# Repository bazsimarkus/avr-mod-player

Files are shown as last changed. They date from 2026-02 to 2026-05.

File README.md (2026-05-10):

# avr-mod-player

An ATmega32-based ProTracker MOD music player with AM29F040B parallel flash memory and stereo PWM audio output. Program a MOD file onto the flash chip, plug it in, and music starts playing.

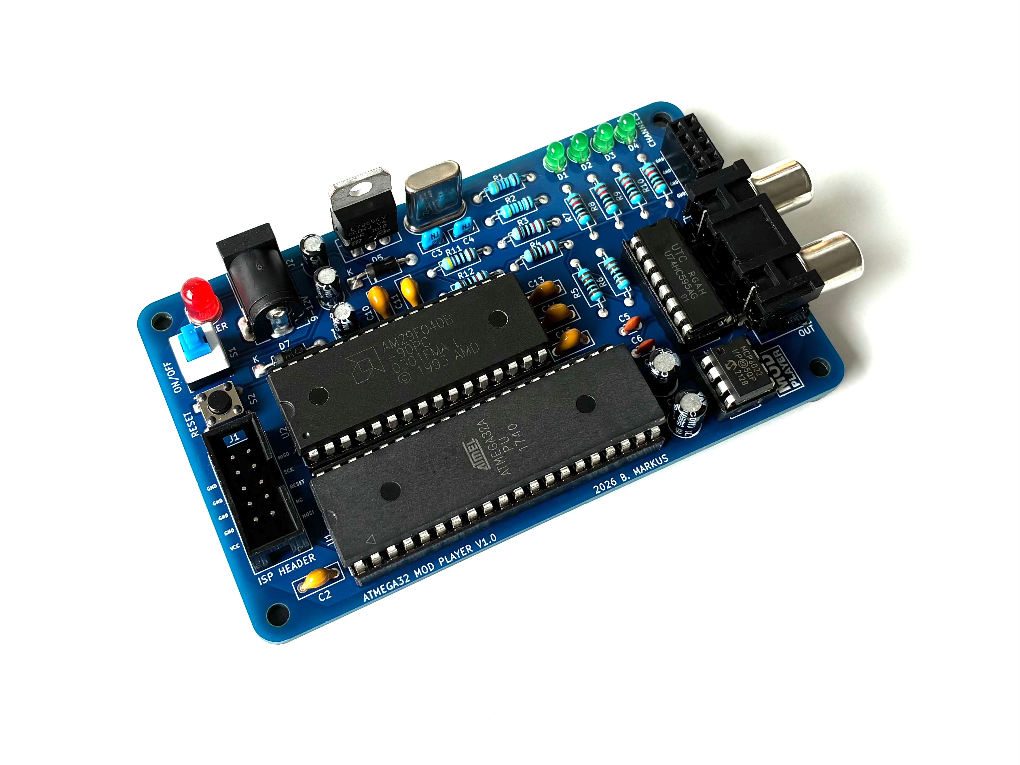
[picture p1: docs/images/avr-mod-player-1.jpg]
AVR MOD Player


---

## Table of Contents

- [Overview](#overview)
- [Features](#features)
- [Getting Started](#getting-started)
  - [What You Need](#what-you-need)
  - [Programming the Flash Chip](#programming-the-flash-chip)
  - [Building and Flashing the Firmware](#building-and-flashing-the-firmware)
- [Schematic](#schematic)
  - [Bill of Materials for the Main Board](#bill-of-materials-for-the-main-board)
- [How It Works](#how-it-works)
  - [Flash Memory Interface](#flash-memory-interface)
  - [Audio Output](#audio-output)
  - [MOD Playback Engine](#mod-playback-engine)
  - [Channel Activity LEDs](#channel-activity-leds)
  - [Power Supply and Protection](#power-supply-and-protection)
- [Speaker Extension Board](#speaker-extension-board)
  - [Bill of Materials for the Speaker Extension Board](#bill-of-materials-for-the-speaker-extension-board)
- [Documentation](#documentation)
- [Acknowledgments](#acknowledgments)

---

## Overview

This is a standalone hardware MOD file player built around the ATmega32A microcontroller. It reads ProTracker .MOD files directly from an AM29F040B parallel NOR flash chip and outputs stereo audio through RCA connectors using PWM and analog filtering. Four green LEDs flash in time with the music, one per channel, showing which voices are active.

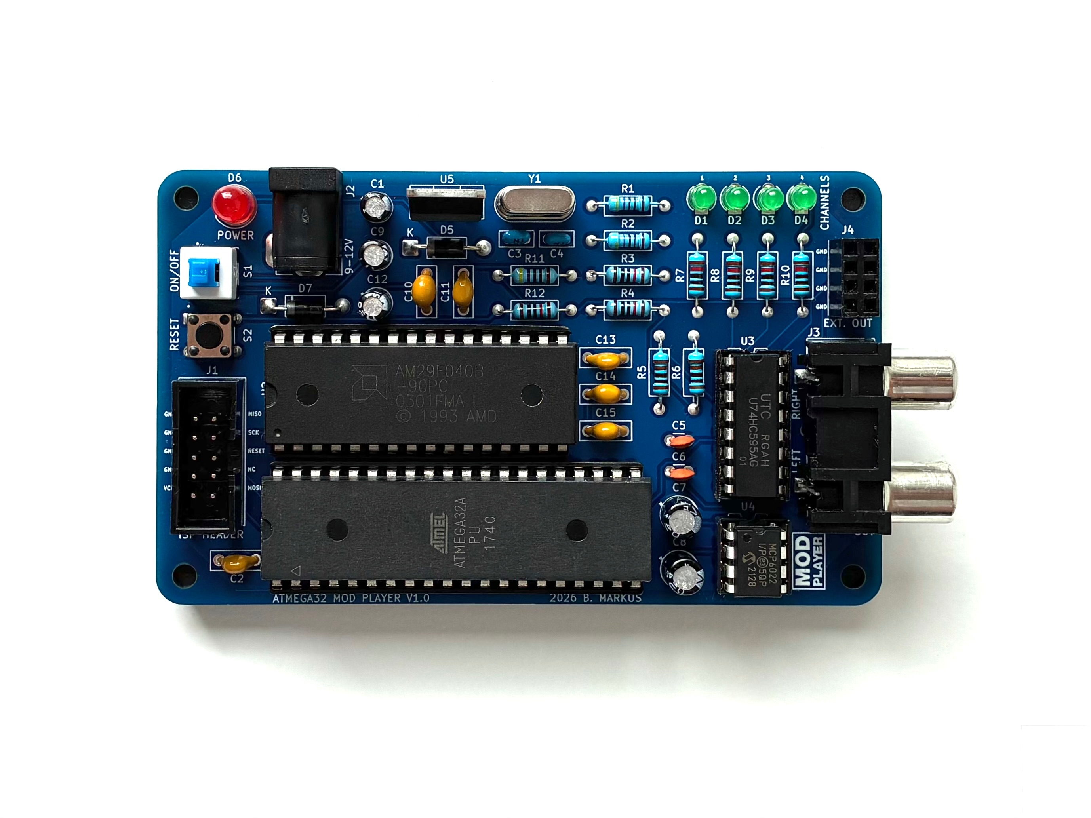
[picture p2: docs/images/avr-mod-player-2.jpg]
AVR MOD Player Top View


The concept is simple: program a MOD file onto the flash chip, plug it into the socket, flip the power switch, and music starts playing immediately. No SD cards, no file systems, no menus. Just a chip full of music and a microcontroller that knows how to play it. If you want to listen to a different track, pull the flash chip out of its socket, erase it, program a new file, and put it back.

My main inspiration was [MadWizard's AVR MOD player](https://www.madwizard.org/electronics/projects/modplayer). That project also used the AM29F040 flash chip, which led me down this path. Since I had no way to program these chips, I ended up designing my own flash programmer, available as a separate project: [amd-flash-programmer](https://github.com/bazsimarkus/amd-flash-programmer).

---

## Features

- ATmega32A microcontroller running at 16 MHz external crystal
- AM29F040B 512KB parallel NOR flash for MOD file storage (socketed for easy swapping)
- Stereo audio output through dual RCA connectors
- MCP6022 dual rail-to-rail op-amp based analog output filtering
- 74HC595 shift register driving four green 3mm channel activity LEDs
- 4-channel ProTracker MOD format playback with effects (arpeggio, portamento, vibrato, volume slide, and more)
- 16 kHz PWM sample rate via Timer1, stereo hard-panned per ProTracker convention (channels 1 and 4 left, channels 2 and 3 right)
- 10-pin ISP header for in-circuit programming via USBasp
- 9-12V DC barrel jack power input with L7805 5V regulator
- 1N5819 Schottky diode protection preventing backfeed between DC jack and ISP programmer power
- ON/OFF toggle switch and reset button
- Pin header for the optional LM386 speaker extension board
- Designed in KiCad, full schematic and PCB files included

---

## Getting Started

### What You Need

- The assembled AVR MOD Player board
- A USBasp programmer (or any AVR ISP programmer)
- A way to program the AM29F040B flash chip (e.g. [amd-flash-programmer](https://github.com/bazsimarkus/amd-flash-programmer))
- A ProTracker .MOD file (max 512KB to fit on the flash chip)
- avr-gcc and avrdude installed on your system
- An RCA audio cable or the speaker extension board for output

### Programming the Flash Chip

1. Find a MOD file you want to play. [The Mod Archive](https://modarchive.org/) has a large collection of free tracks. Some personal favorites: Maktone - Vanishing Colors, LHS - It's a Good Day, Random Voice - Monday.

2. Remove the AM29F040B from its socket on the player board.

3. Program the raw .MOD file onto the flash chip starting at address 0x00000 using the [amd-flash-programmer](https://github.com/bazsimarkus/amd-flash-programmer) or any compatible flash programmer.

4. Place the programmed flash chip back into the socket on the player board.

5. Flip the power switch. The music starts playing immediately.

### Building and Flashing the Firmware

The firmware is a single C source file (`avr-mod-player/main.c`) targeting the ATmega32A at 16 MHz. It has no external dependencies beyond standard avr-libc. It links against libm for the math routines.

#### Method 1: Command line with avr-gcc and avrdude

Install avr-gcc and avrdude for your platform (on Debian/Ubuntu: `sudo apt install gcc-avr avr-libc avrdude`; on Windows, install WinAVR or the Microchip AVR toolchain).

Navigate to the `avr-mod-player` directory and run:

```sh
avr-gcc -mmcu=atmega32 -DF_CPU=16000000UL -O1 \
    -funsigned-char -funsigned-bitfields \
    -ffunction-sections -fdata-sections \
    -fpack-struct -fshort-enums \
    -Wall -o main.elf main.c -lm

avr-objcopy -O ihex main.elf main.hex
```

Then flash with your USBasp programmer:

```sh
avrdude -c usbasp -p m32 -U flash:w:main.hex
```

#### Method 2: MPLAB X IDE

The repository includes an MPLAB X IDE project in the `avr-mod-player/nbproject` directory. The project has two build configurations:

- **default**: Compiles only, produces the hex file.
- **flash**: Identical to default, but runs avrdude automatically after a successful build to flash the connected board via USBasp. The post-build step is:

```
avrdude -c usbasp -p m32 -U flash:w:${ImagePath}
```

With the flash configuration selected, clicking Build Main Project compiles the firmware and programs the board in a single step.

The project was developed with MPLAB X IDE v6.25 and the Microchip ATmega_DFP 3.3.279 device pack. The compiler is avr-gcc 5.4.0.

---

## Schematic

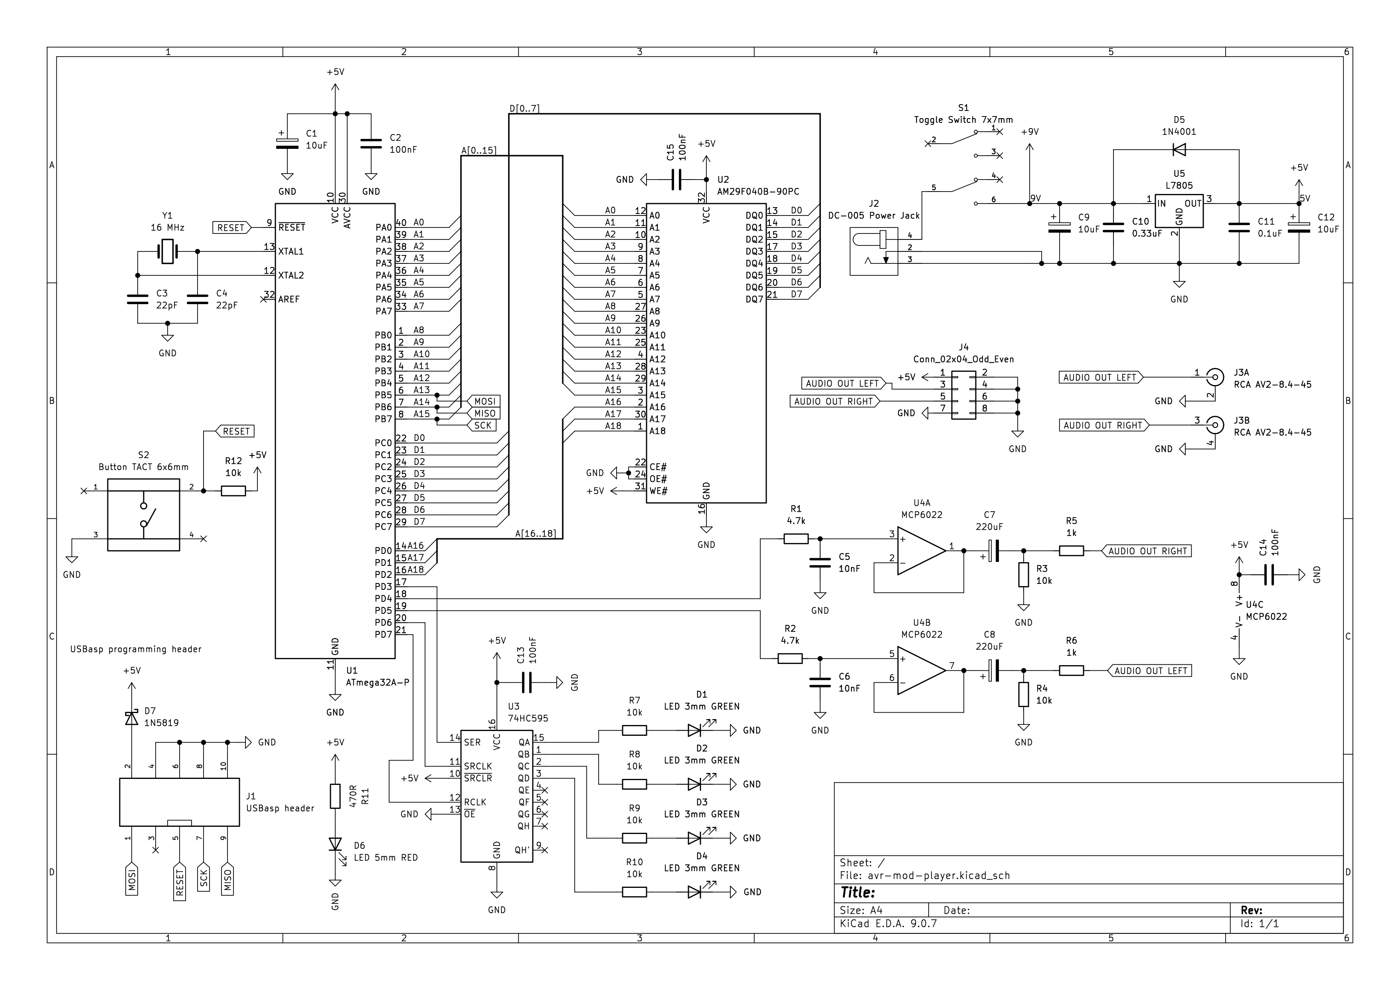
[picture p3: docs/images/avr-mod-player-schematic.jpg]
AVR MOD Player Schematic


The full KiCad project files (schematic, PCB layout, and project file) are in the `schematic/` directory.

### Bill of Materials for the Main Board

| Ref | Value | Description | Qty |
|-----|---|---|-----|
| **ICs** ||||
| U1 | ATmega32A-P | 16 MHz, 32 KB Flash, 2 KB SRAM, DIP-40 | 1 |
| U2 | AM29F040B-90PC | 4 Mbit NOR flash (512K×8), 90 ns, DIP-32 | 1 |
| U3 | 74HC595 | 8-bit shift register, 3-state outputs, DIP-16 | 1 |
| U4 | MCP6022 | Dual rail-to-rail op-amp, DIP-8 | 1 |
| U5 | L7805 | 5 V 1.5 A linear voltage regulator, TO-220 | 1 |
| **Crystal** ||||
| Y1 | 16 MHz | HC49-U vertical | 1 |
| **Capacitors (polarized)** ||||
| C1 | 10 µF | Electrolytic, radial, D4.0 mm P2.00 mm | 1 |
| C7 | 220 µF | Electrolytic, radial, D5.0 mm P2.00 mm | 1 |
| C8 | 220 µF | Electrolytic, radial, D5.0 mm P2.00 mm | 1 |
| C9 | 10 µF | Electrolytic, radial, D4.0 mm P2.00 mm | 1 |
| C12 | 10 µF | Electrolytic, radial, D4.0 mm P2.00 mm | 1 |
| **Capacitors (unpolarized)** ||||
| C2 | 100 nF | Film/MLCC, P5.00 mm | 1 |
| C3 | 22 pF | Ceramic, P2.50 mm | 1 |
| C4 | 22 pF | Ceramic, P2.50 mm | 1 |
| C5 | 10 nF | Ceramic disc, P2.50 mm | 1 |
| C6 | 10 nF | Ceramic disc, P2.50 mm | 1 |
| C10 | 0.33 µF | Film, P5.00 mm | 1 |
| C11 | 0.1 µF | Film, P5.00 mm | 1 |
| C13 | 100 nF | Film/MLCC, P5.00 mm | 1 |
| C14 | 100 nF | Film/MLCC, P5.00 mm | 1 |
| C15 | 100 nF | Film/MLCC, P5.00 mm | 1 |
| **Resistors (all 1/4 W axial)** ||||
| R1, R2 | 4.7 kΩ | PWM filter pull-up | 2 |
| R3, R4, R7, R8, R9, R10, R12 | 10 kΩ | Pull-ups / biasing / LED current limit | 7 |
| R5, R6 | 1 kΩ | Audio output series | 2 |
| R11 | 470 Ω | Power LED current limiter | 1 |
| **Diodes** ||||
| D1, D2, D3, D4 | LED 3 mm green | Channel activity indicators | 4 |
| D5 | 1N4001 | 50 V 1 A rectifier, DO-41 | 1 |
| D6 | LED 5 mm red | Power indicator | 1 |
| D7 | 1N5819 | 40 V 1 A Schottky, DO-41 (reverse polarity protection) | 1 |
| **Switches** ||||
| S1 | Toggle 7×7 mm DPDT | Power on/off (E-Switch TL2230OAF140) | 1 |
| S2 | Tact 6×6 mm | Reset (CUI TS02-66-100-BK-260-LCR-D) | 1 |
| **Connectors** ||||
| J1 | 2×5 shrouded box header | USBasp ISP header (Würth 61201021621) | 1 |
| J2 | DC-005 barrel jack | 2.1 mm center-positive | 1 |
| J3 | Dual RCA (AV2-8.4-45) | Stereo audio output | 1 |
| J4 | 2×4 pin socket | Speaker board expansion, 2.54 mm | 1 |
| **Recommended sockets** ||||
| - | 40-pin DIP socket | For U1 (ATmega32A) | 1 |
| - | 32-pin DIP socket | For U2 (AM29F040B) | 1 |
| - | 16-pin DIP socket | For U3 (74HC595) | 1 |
| - | 8-pin DIP socket | For U4 (MCP6022) | 1 |

---

## How It Works

### Flash Memory Interface

The AM29F040B is a 512KB parallel NOR flash chip in a 32-pin DIP package. The ATmega32A addresses it using nearly all of its available I/O pins:

- PORTA (PA0-PA7): Address lines A0-A7
- PORTB (PB0-PB7): Address lines A8-A15
- PORTD (PD0-PD2): Address lines A16-A18
- PORTC (PC0-PC7): Data bus DQ0-DQ7 (configured as input)

This gives 19 address lines, enough for the full 512KB address space. The chip enable (CE#) and output enable (OE#) pins are active (directly connected to ground), meaning the flash is always outputting data on the bus. The write enable (WE#) pin is pulled high permanently with a resistor, since the player board never writes to the flash. This simplified design was necessary because the ATmega32A does not have enough free pins to control WE# dynamically.

Reading a byte from flash is a single function call: set PORTA, PORTB, and the lower bits of PORTD to the desired address, wait two CPU cycles for the flash access time, then read PINC. At 16 MHz, this gives about 187 ns of access time, well within the 90 ns rating of the AM29F040B-90PC.

### Audio Output

Stereo audio is generated using Timer1 in 8-bit fast PWM mode. The two PWM outputs (OC1A on PD5 for left, OC1B on PD4 for right) run at a carrier frequency of 62.5 kHz (16 MHz / 256), which is well above the audible range.

The raw PWM signals pass through a low-pass filter built around the MCP6022 dual rail-to-rail op-amp. Each channel has its own filter section: a 10nF capacitor and a 4.7k resistor form the RC low-pass, and the op-amp buffers and drives the output through a 220uF coupling capacitor to the RCA connector. The coupling capacitor removes the DC offset so only the audio AC signal reaches the amplifier or speakers.

### MOD Playback Engine

The firmware implements a ProTracker-compatible 4-channel MOD player. Timer0 fires an interrupt at exactly 16,000 Hz, which pulls samples from a ring buffer and writes them to the PWM registers. The main loop continuously fills that buffer by mixing the four channels.

The MOD file format stores music as a sequence of patterns. Each pattern has 64 rows, and each row has four cells (one per channel). Each cell can trigger a sample at a given pitch, change the volume, or apply an effect. At startup, the firmware parses the MOD header from flash to locate the sample data and pattern data, then begins sequencing through the song.

The engine supports the following ProTracker effects:

- 0xy: Arpeggio
- 1xx: Portamento up
- 2xx: Portamento down
- 3xx: Tone portamento
- 4xy: Vibrato
- 9xx: Sample offset
- Axy: Volume slide
- Bxx: Pattern jump
- Cxx: Set volume
- Dxx: Pattern break
- Fxx: Set speed/tempo
- E1y/E2y: Fine portamento
- E9y: Retrigger note
- EAy/EBy: Fine volume slide
- ECy: Note cut

Pitch is calculated using 16.16 fixed-point arithmetic. The playback step for each channel is derived from the Amiga PAL clock constant (3,546,895 Hz) divided by the channel's current period value, scaled to the 16 kHz output rate. This gives sample-accurate pitch reproduction matching the original Amiga hardware.

The MOD file format specification used to build this player is included in the repository at `docs/mod-spec.txt` (sourced from [eblong.com/zarf/blorb/mod-spec.txt](https://www.eblong.com/zarf/blorb/mod-spec.txt)).

### Channel Activity LEDs

Four green 3mm LEDs (D1-D4) are driven by a 74HC595 shift register connected to three pins on PORTD. Each time a note triggers on a channel, the corresponding LED lights up for approximately 60 milliseconds (3 sequencer ticks). This creates a short flash locked to the beat, giving a visual indication of which channels are active. The LEDs are updated once per sequencer tick in the main audio loop.

### Power Supply and Protection

The board is powered from a 9-12V DC barrel jack. An L7805 voltage regulator provides the 5V rail for all digital and analog circuitry. A 1N4001 rectifier diode on the DC input provides reverse polarity protection.

A 1N5819 Schottky diode sits between the ISP header's VCC pin and the board's 5V rail. When the board is powered from the DC jack, the Schottky diode prevents the regulated 5V from backfeeding into the programmer. When the board is powered from the programmer (for firmware development without the DC supply connected), the Schottky diode conducts and powers the board from the programmer's VCC. This protects both the L7805 regulator and the programmer from conflicting voltage sources.

---

## Speaker Extension Board

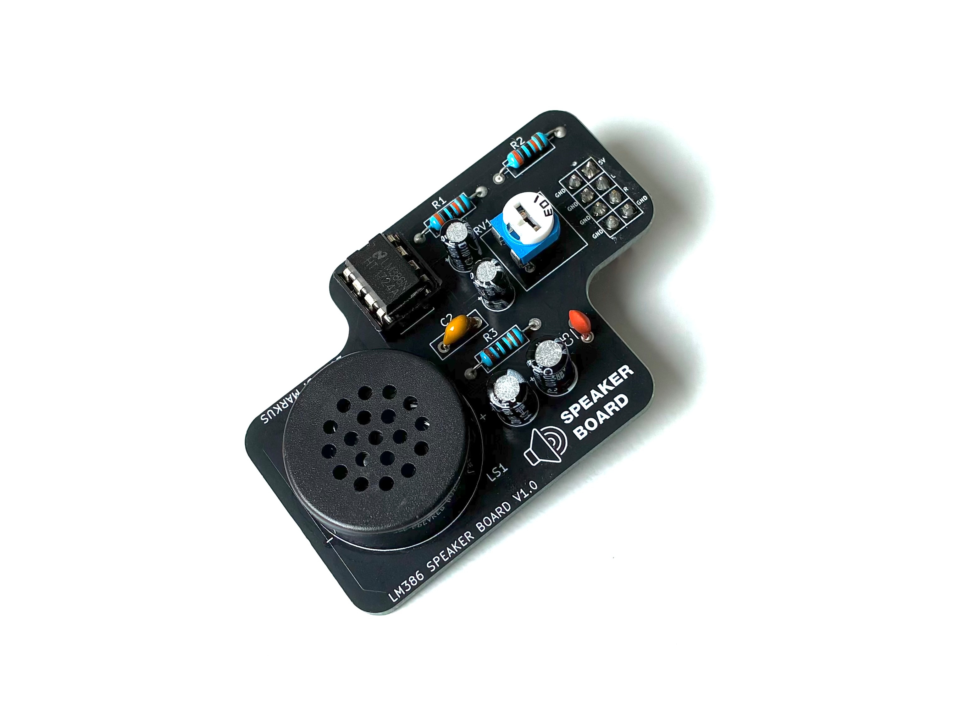
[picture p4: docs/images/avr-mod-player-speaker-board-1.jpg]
Speaker Extension Board


An optional LM386 speaker extension board can be connected to the 2x4 pin header (J4) on the main board. It mixes the left and right channels through two 300k resistors into a volume trimmer, feeds the signal through an LM386 audio power amplifier, and drives a small 23mm 8-ohm speaker. The board connects directly to the pin header and receives both audio signals and power from the main board.

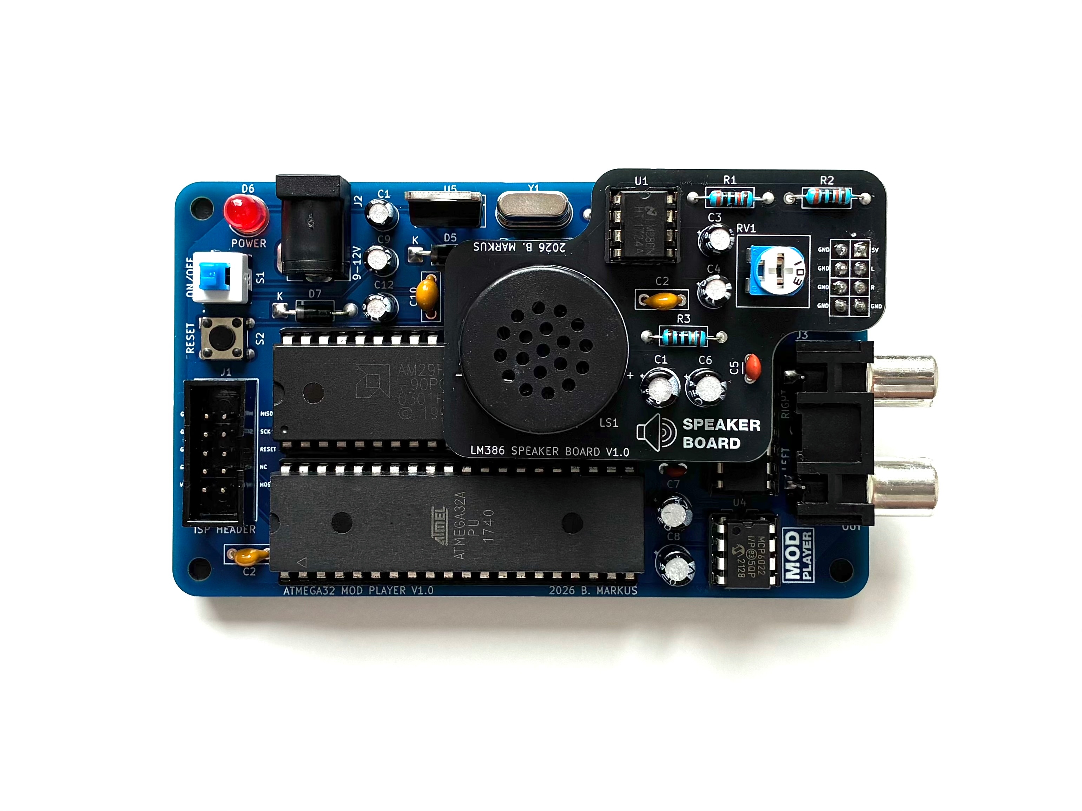
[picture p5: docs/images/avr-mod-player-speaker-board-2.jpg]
Speaker Extension Board connected to the main board


The KiCad project files for the speaker board are in `extension-boards/speaker-board/`.

### Bill of Materials for the Speaker Extension Board

| Ref | Value | Description | Qty |
|-----|---|---|-----|
| **ICs** ||||
| U1 | LM386 | Low-voltage audio power amplifier, DIP-8 | 1 |
| **Capacitors (polarized)** ||||
| C1 | 100 µF | Electrolytic, radial, D5.0 mm P2.00 mm | 1 |
| C3 | 1 µF | Electrolytic, radial, D4.0 mm P2.00 mm | 1 |
| C4 | 10 µF | Electrolytic, radial, D4.0 mm P2.00 mm (bypass) | 1 |
| C6 | 220 µF | Electrolytic, radial, D5.0 mm P2.00 mm (output coupling) | 1 |
| **Capacitors (unpolarized)** ||||
| C2 | 0.1 µF | Film, P5.00 mm (decoupling) | 1 |
| C5 | 47 nF | Ceramic disc, P2.50 mm (Zobel network) | 1 |
| **Resistors (all 1/4 W axial)** ||||
| R1, R2 | 300 kΩ | Input mixing (L + R → mono) | 2 |
| R3 | 10 Ω | Zobel network series | 1 |
| **Potentiometer** ||||
| RV1 | Trimpot 3362-P | Volume adjustment | 1 |
| **Speaker** ||||
| LS1 | CVS-2308 | 23 mm, 0.1 W, 8 Ω (CUI Devices) | 1 |
| **Connectors** ||||
| J1 | 2×4 pin header | Mates with main board J4, 2.54 mm vertical | 1 |
| **Recommended sockets** ||||
| - | 8-pin DIP socket | For U1 (LM386) | 1 |

---

## Documentation

The `docs/` directory contains:

- `mod-spec.txt`: The ProTracker MOD file format specification used as reference for the playback engine (from [eblong.com](https://www.eblong.com/zarf/blorb/mod-spec.txt))

---

## Acknowledgments

- [MadWizard](https://www.madwizard.org/electronics/projects/modplayer) for the original AVR MOD player project that inspired this build
- [The Mod Archive](https://modarchive.org/) for the collection of freely available MOD files
- The ProTracker MOD format specification from [eblong.com](https://www.eblong.com/zarf/blorb/mod-spec.txt)

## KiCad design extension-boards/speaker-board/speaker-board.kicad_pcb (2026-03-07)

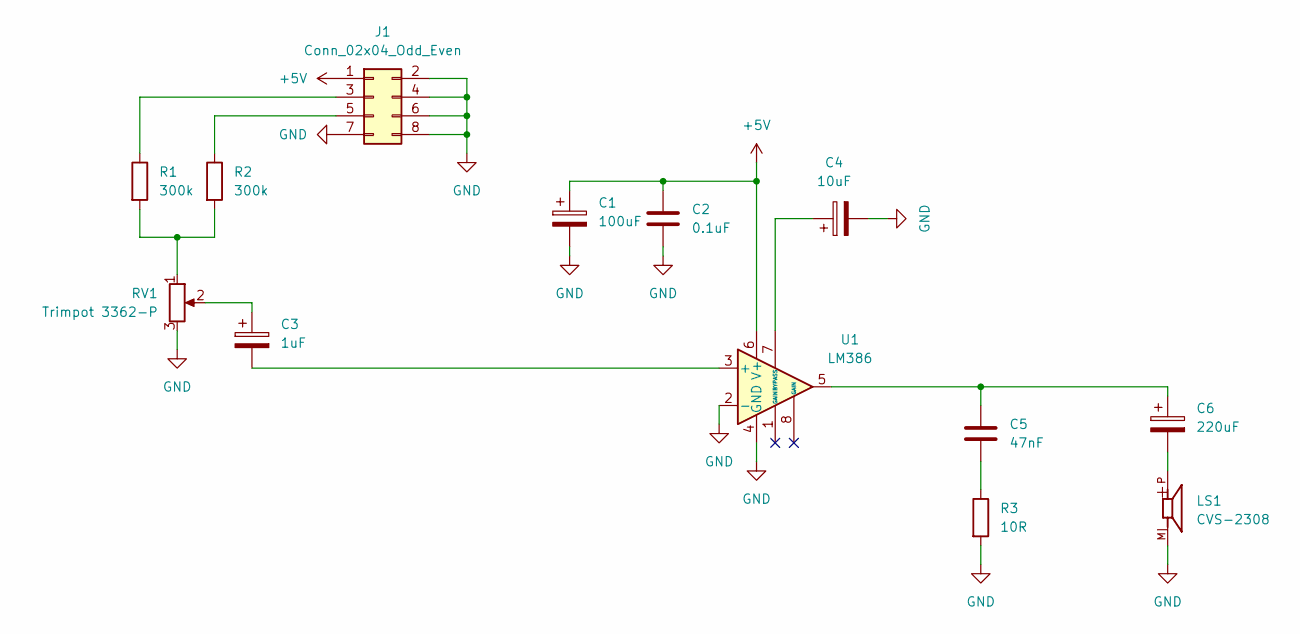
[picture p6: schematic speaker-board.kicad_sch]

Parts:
C1: 100uF; CP_Radial_D5.0mm_P2.00mm
C2: 0.1uF; C_100nF_L7.0mm_W2.5mm_P5.00mm
C3: 1uF; CP_Radial_D4.0mm_P2.00mm
C4: 10uF; CP_Radial_D4.0mm_P2.00mm
C5: 47nF; C_Disc_D3.0mm_W1.6mm_P2.50mm
C6: 220uF; CP_Radial_D5.0mm_P2.00mm
J1: Conn_02x04_Odd_Even; PinHeader_2x04_P2.54mm_Vertical
LS1: CVS-2308; SPKR_CVS-2308
R1, R2: 300k; R_10k_Axial_DIN0207
R3: 10R; R_10k_Axial_DIN0207
RV1: Trimpot 3362-P; Trimpot 3386F
U1: LM386; DIP-8_W7.62mm

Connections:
+5V: C1.1, C2.2, J1.1, U1.6 (V+)
GND: C1.2, C2.1, C4.2, J1.2, J1.4, J1.6, J1.7, J1.8, LS1.M, R3.2, RV1.3, U1.2 (-), U1.4 (GND)
unnamed: C3.1, RV1.2
unnamed: C5.1, R3.1
unnamed: C5.2, C6.1, U1.5
unnamed: C6.2, LS1.P
unnamed: J1.3, R1.1
unnamed: J1.5, R2.1
unnamed: R1.2, R2.2, RV1.1
unnamed: C3.2, U1.3 (+)
unnamed: C4.1, U1.7 (BYPASS)

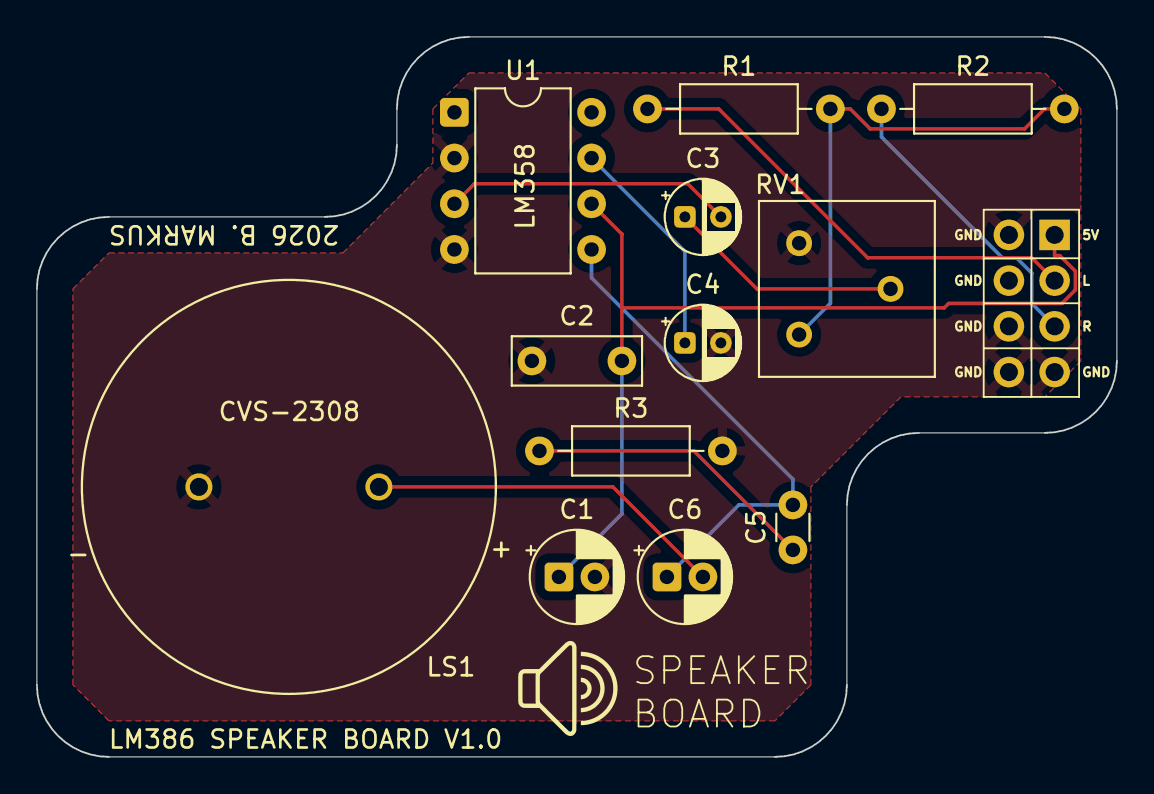
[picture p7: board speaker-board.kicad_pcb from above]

Board: 2 copper layers, 60.0 x 40.0 mm, 14 parts (1 on the bottom side), 11 nets.

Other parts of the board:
G1: LOGO

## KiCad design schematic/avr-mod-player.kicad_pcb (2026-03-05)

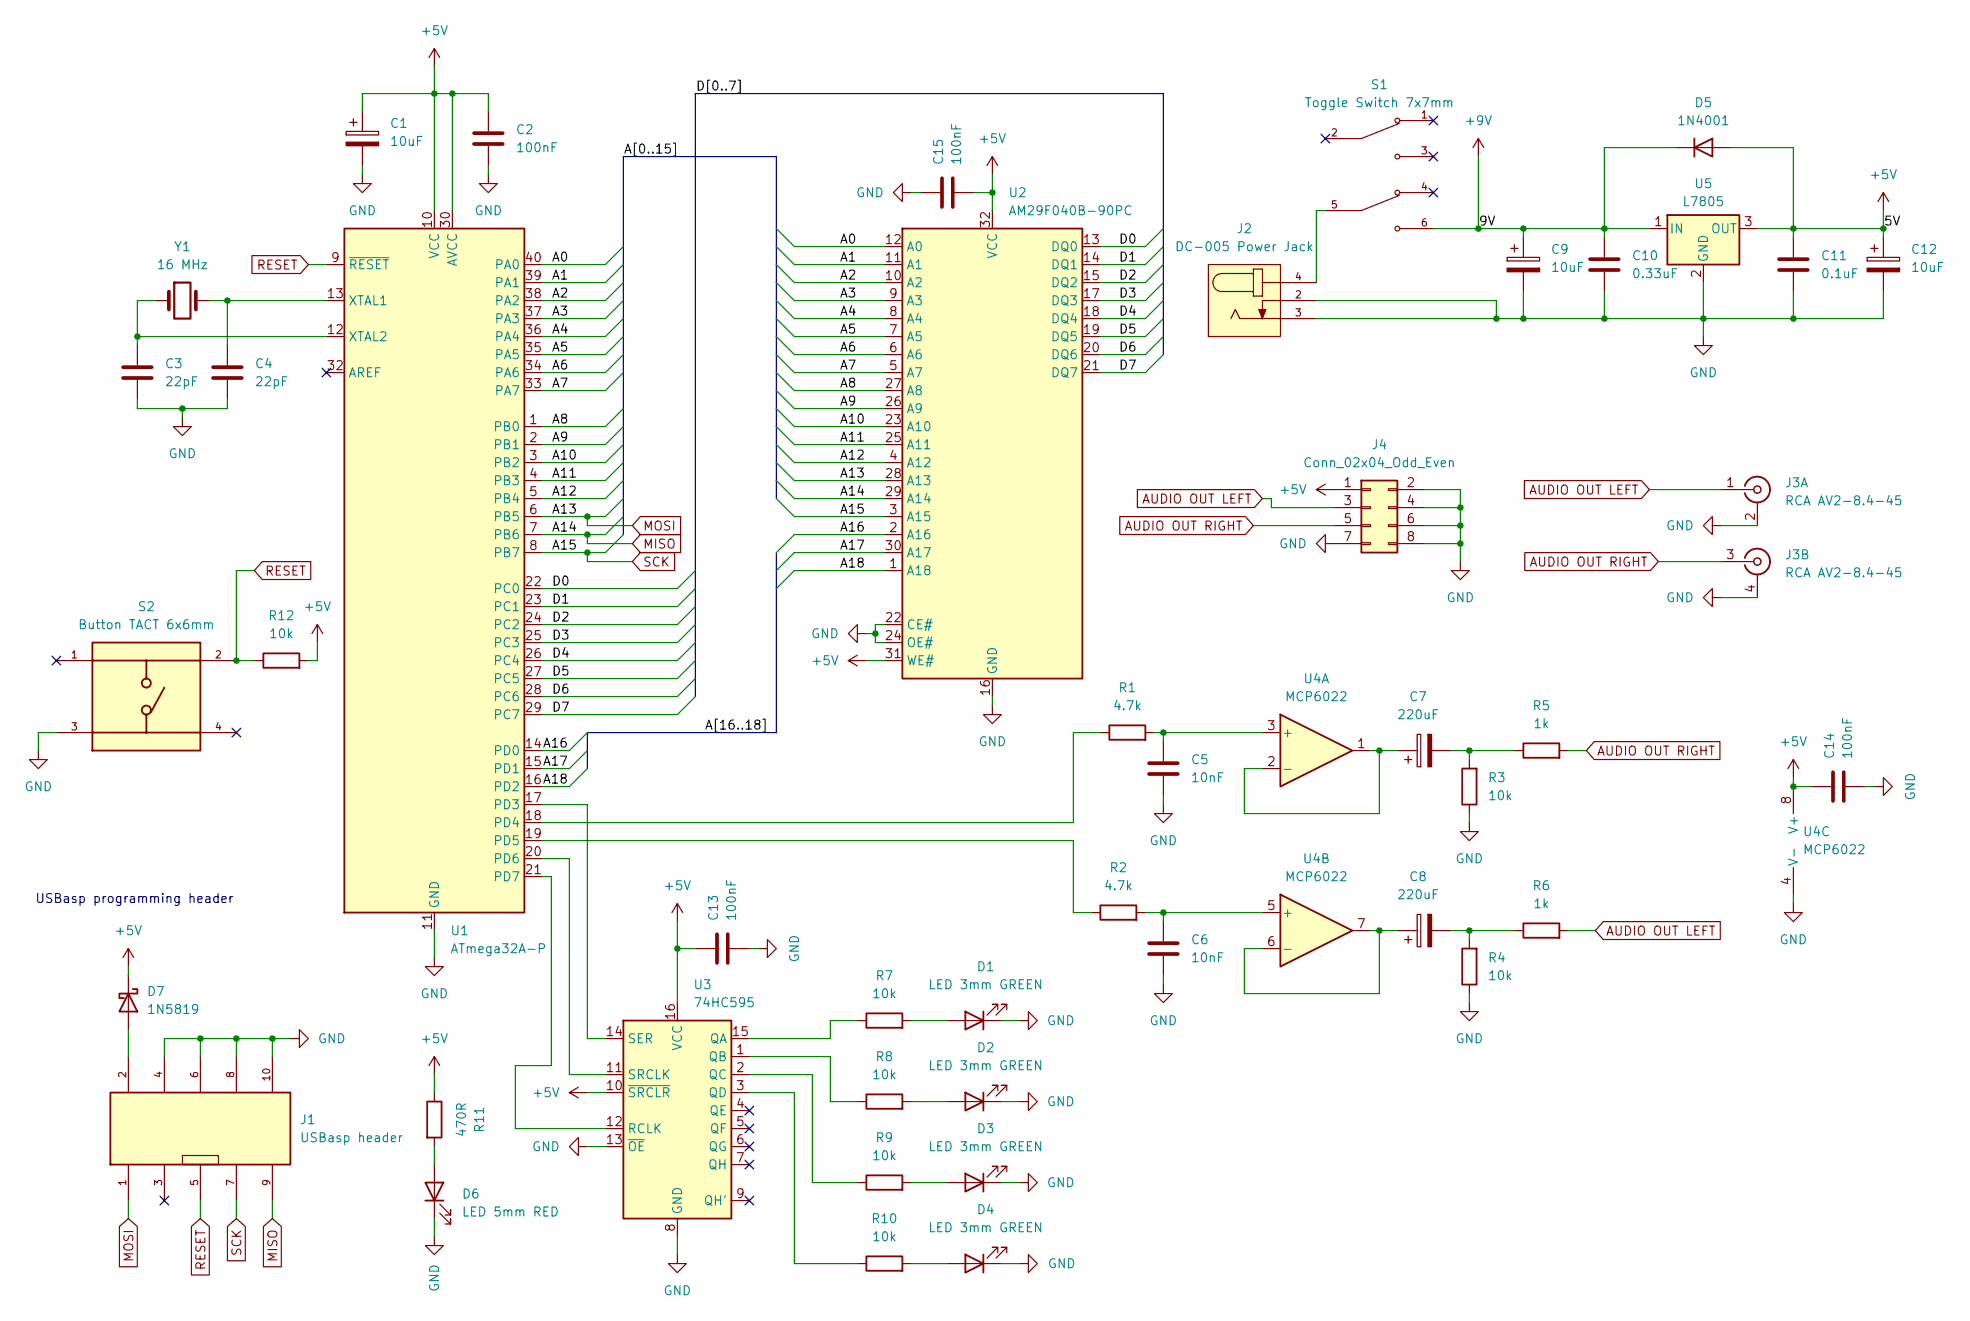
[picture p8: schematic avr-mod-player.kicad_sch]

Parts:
C1, C9, C12: 10uF; CP_Radial_D4.0mm_P2.00mm
C2, C13, C14, C15: 100nF; C_100nF_L7.0mm_W2.5mm_P5.00mm
C3, C4: 22pF; C_Rect_L4.6mm_W2.0mm_P2.50mm_MKS02_FKP02
C5, C6: 10nF; C_Disc_D3.0mm_W1.6mm_P2.50mm
C7, C8: 220uF; CP_Radial_D5.0mm_P2.00mm
C10: 0.33uF; C_100nF_L7.0mm_W2.5mm_P5.00mm
C11: 0.1uF; C_100nF_L7.0mm_W2.5mm_P5.00mm
D1, D2, D3, D4: LED 3mm GREEN; LED_D3.0mm_GREEN
D5: 1N4001; D_DO-41_SOD81_P10.16mm_Horizontal
D6: LED 5mm RED; LED_D5.0mm_RED
D7: 1N5819; D_DO-41_SOD81_P10.16mm_Horizontal
J1: USBasp header; 2x5 Shrouded Box Header
J2: DC-005 Power Jack
J3: RCA AV2-8.4-45; AV2-8.4-45
J4: Conn_02x04_Odd_Even; PinSocket_2x04_P2.54mm_Vertical
R1, R2: 4.7k; R_470_Axial_DIN0207
R3, R4, R12: 10k; R_10k_Axial_DIN0207
R5, R6: 1k; R_1k_Axial_DIN0207
R7, R8, R9, R10: 10k; R_470_Axial_DIN0207
R11: 470R; R_470_Axial_DIN0207
S1: Toggle Switch 7x7mm; PARTREV E; DigiKey_Part_Number EG6032-ND
S2: Button TACT 6x6mm; PARTREV 1.0
U1: ATmega32A-P; DIP-40_W15.24mm
U2: AM29F040B-90PC; DIP-32_W15.24mm
U3: 74HC595; DIP-16_W7.62mm
U4: MCP6022; DIP-8_W7.62mm
U5: L7805; TO-220-3_Vertical
Y1: 16 MHz; Crystal_HC49-U_Vertical

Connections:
+5V: C1.1, C2.1, C11.2, C12.1, C13.1, C14.1, C15.2, D5.2 (A), D7.1 (K), J4.1, R11.1, R12.2, U1.10 (VCC), U1.30 (AVCC), U2.31 (WE#), U2.32 (VCC), U3.10 (~SRCLR), U3.16 (VCC), U4.8 (V+), U5.3 (OUT)
+9V: C9.1, C10.2, D5.1 (K), S1.6, U5.1 (IN)
/A0: U1.40 (PA0), U2.12 (A0)
/A1: U1.39 (PA1), U2.11 (A1)
/A2: U1.38 (PA2), U2.10 (A2)
/A3: U1.37 (PA3), U2.9 (A3)
/A4: U1.36 (PA4), U2.8 (A4)
/A5: U1.35 (PA5), U2.7 (A5)
/A6: U1.34 (PA6), U2.6 (A6)
/A7: U1.33 (PA7), U2.5 (A7)
/A8: U1.1 (PB0), U2.27 (A8)
/A9: U1.2 (PB1), U2.26 (A9)
/A10: U1.3 (PB2), U2.23 (A10)
/A11: U1.4 (PB3), U2.25 (A11)
/A12: U1.5 (PB4), U2.4 (A12)
/A16: U1.14 (PD0), U2.2 (A16)
/A17: U1.15 (PD1), U2.30 (A17)
/A18: U1.16 (PD2), U2.1 (A18)
/D0: U1.22 (PC0), U2.13 (DQ0)
/D1: U1.23 (PC1), U2.14 (DQ1)
/D2: U1.24 (PC2), U2.15 (DQ2)
/D3: U1.25 (PC3), U2.17 (DQ3)
/D4: U1.26 (PC4), U2.18 (DQ4)
/D5: U1.27 (PC5), U2.19 (DQ5)
/D6: U1.28 (PC6), U2.20 (DQ6)
/D7: U1.29 (PC7), U2.21 (DQ7)
AUDIO OUT LEFT: J3.1 (In1), J4.3, R6.2
AUDIO OUT RIGHT: J3.3 (In2), J4.5, R5.2
GND: C1.2, C2.2, C3.2, C4.2, C5.2, C6.2, C9.2, C10.1, C11.1, C12.2, C13.2, C14.2, C15.1, D1.1 (K), D2.1 (K), D3.1 (K), D4.1 (K), D6.1 (K), J1.4, J1.6, J1.8, J1.10, J2.2, J2.3, J3.2 (Ext1), J3.4 (Ext2), J4.2, J4.4, J4.6, J4.7, J4.8, R3.1, R4.1, S2.3, U1.11 (GND), U1.31 (GND), U2.16 (GND), U2.22 (CE#), U2.24 (OE#), U3.8 (GND), U3.13 (~OE), U4.4 (V-), U5.2 (GND)
MISO: J1.9, U1.7 (PB6), U2.29 (A14)
MOSI: J1.1, U1.6 (PB5), U2.28 (A13)
unnamed: C7.2, R3.2, R5.1
unnamed: C8.2, R4.2, R6.1
unnamed: D1.2 (A), R7.2
unnamed: D2.2 (A), R8.2
unnamed: D3.2 (A), R9.2
unnamed: D4.2 (A), R10.2
unnamed: D6.2 (A), R11.2
unnamed: D7.2 (A), J1.2
unnamed: J2.4, S1.5
unnamed: U1.17 (PD3), U3.14 (SER)
unnamed: R1.1, U1.18 (PD4)
unnamed: R2.1, U1.19 (PD5)
unnamed: U1.20 (PD6), U3.11 (SRCLK)
unnamed: U1.21 (PD7), U3.12 (RCLK)
unnamed: C4.1, U1.13 (XTAL1), Y1.2
unnamed: C3.1, U1.12 (XTAL2), Y1.1
unnamed: R7.1, U3.15 (QA)
unnamed: R8.1, U3.1 (QB)
unnamed: R9.1, U3.2 (QC)
unnamed: R10.1, U3.3 (QD)
unnamed: C5.1, R1.2, U4.3 (+)
unnamed: C7.1, U4.1, U4.2 (-)
unnamed: C6.1, R2.2, U4.5 (+)
unnamed: C8.1, U4.6 (-), U4.7
RESET: J1.5, R12.1, S2.2, U1.9 (~RESET)
SCK: J1.7, U1.8 (PB7), U2.3 (A15)

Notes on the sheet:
USBasp programming header

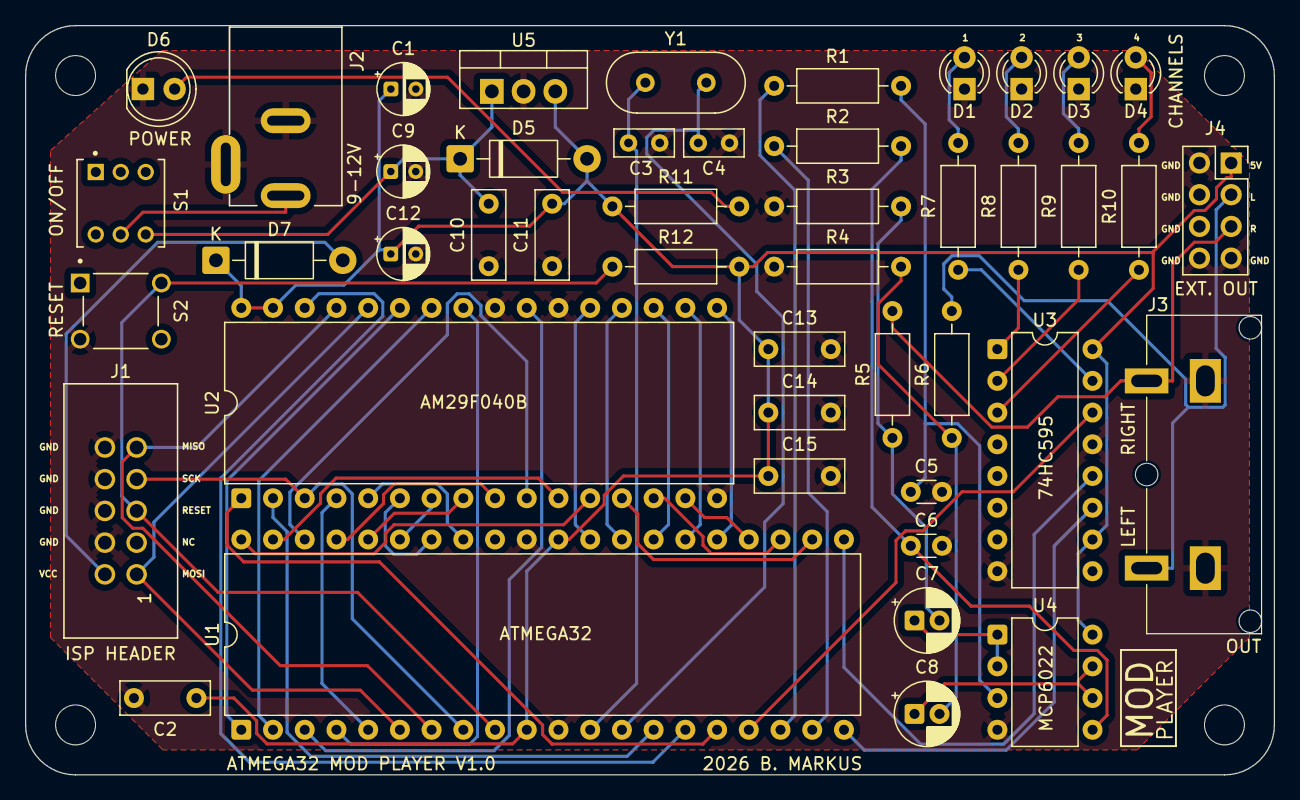
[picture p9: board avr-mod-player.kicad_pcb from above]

Board: 2 copper layers, 100.0 x 60.0 mm, 50 parts (0 on the bottom side), 57 nets.

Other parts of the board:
MH1, MH2, MH3, MH4: MountingHole_3.2mm_M3_DIN965

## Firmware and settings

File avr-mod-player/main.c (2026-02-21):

/*
 * main.c ? ATmega32A MOD Player (ProTracker-compatible, 4-channel)
 *
 * Hardware:
 *   - AM29F040B parallel NOR flash (512KB) hard-wired to PORTA (A0-A7),
 *     PORTB (A8-A15), and PD0..PD2 (A16-A18). PORTC = data bus (input).
 *   - Stereo PWM audio output via Timer1: OC1A (PD5) = Left, OC1B (PD4) = Right.
 *   - 74HC595 shift register for 4-channel LED visualisation via PD3/PD6/PD7.
 *   - Timer0 fires the audio ISR at exactly 16,000 Hz.
 *
 * Converted from Arduino sketch to bare-metal avr-gcc / MPLAB X.
 * Minimal changes: setup() -> init code at top of main(), loop() -> while(1).
 * All functionality is identical to the original Arduino version.
 *
 * Toolchain: MPLAB X IDE + avr-gcc (or XC8 in C99 mode)
 * Target:    ATmega32A @ 16 MHz external crystal
 */

#include <avr/io.h>
#include <avr/interrupt.h>
#include <avr/pgmspace.h>

// =========================================================================
// DEFINES & CONSTANTS
// =========================================================================

#define SAMPLE_RATE      16000
#define AMIGA_PAL_CLOCK  3546895UL

// 16.16 fixed-point constant for playback step calculation.
// step = STEP_CONSTANT / period  =>  gives the number of sample-data bytes
// to advance per output sample at 16 kHz, in 16.16 fixed-point.
// Derivation: (AMIGA_PAL_CLOCK * 65536) / SAMPLE_RATE = 14528082
#define STEP_CONSTANT  14528082UL

#define NUM_SAMPLES       31
#define CHANNELS           4
#define ROWS_PER_PATTERN  64
#define BUF_SIZE         128   // Must be a power of two (ring-buffer)

// Shift Register Pins (all on PORTD)
#define SER_PIN    PD3   // Serial data in
#define SRCLK_PIN  PD6   // Shift register clock
#define RCLK_PIN   PD7   // Latch / storage clock

// =========================================================================
// PROGMEM TABLES
// =========================================================================

// Sine table for vibrato effect (effect 0x4).
// Range: -127 .. +127, 64 entries covering one full cycle.
static const int8_t sine_table[64] PROGMEM = {
      0,  12,  25,  37,  49,  60,  71,  81,  90,  98, 106, 112, 117, 122, 125, 126,
    127, 126, 125, 122, 117, 112, 106,  98,  90,  81,  71,  60,  49,  37,  25,  12,
      0, -12, -25, -37, -49, -60, -71, -81, -90, -98,-106,-112,-117,-122,-125,-126,
   -127,-126,-125,-122,-117,-112,-106, -98, -90, -81, -71, -60, -49, -37, -25, -12
};

// Pre-computed 16.16 fixed-point multipliers for arpeggio (effect 0x0).
// Each entry approximates pow(2, -semitone/12) * 65536.
// Index 0 = unison (65536 ? 1.0), index 12 = one octave down (32768 = 0.5), etc.
// Usage: new_period = (period * arp_factor[semitones]) >> 16
static const uint16_t arp_factor[16] PROGMEM = {
    65535, 61858, 58386, 55109, 52016, 49097, 46341, 43740,
    41285, 38968, 36781, 34716, 32768, 30929, 29193, 27554
};

// =========================================================================
// DATA STRUCTURES
// =========================================================================

// Describes one of the 31 sample slots stored in the MOD file header.
typedef struct {
    uint32_t data_offset;   // Absolute byte address of sample PCM data in flash
    uint32_t length;        // Total sample length in bytes
    uint32_t loop_start;    // Loop start offset in bytes
    uint32_t loop_length;   // Loop region length in bytes (<=2 means no loop)
    uint8_t  volume;        // Default volume (0-64)
} Sample;

// Global module metadata, parsed once at startup from flash.
typedef struct {
    Sample   samples[NUM_SAMPLES];
    uint8_t  num_song_positions;   // How many entries in the order table are valid
    uint8_t  restart_position;     // Song restart position (often unused)
    uint8_t  order[128];           // Pattern play order table
    uint8_t  num_patterns;         // Total number of unique patterns
    uint32_t pattern_data_offset;  // Byte address in flash where pattern data begins
} Module;

// Per-channel runtime state for the audio engine.
typedef struct {
    // Sample data (copied from Sample struct when a note triggers)
    uint32_t data_offset;
    uint32_t length;
    uint32_t loop_start;
    uint32_t loop_length;
    uint8_t  volume;        // Current volume (0-64), may be altered by effects

    uint32_t position;      // Current playback position in sample, 16.16 fixed-point
    uint32_t step;          // Playback increment per output sample, 16.16 fixed-point
    uint16_t period;        // Current Amiga period value (controls pitch). 0 = silent.

    // Effect memory (persists across ticks / rows)
    uint16_t porta_target;  // Tone portamento (0x3) destination period
    uint8_t  porta_speed;   // Tone portamento slide speed
    uint8_t  vib_speed;     // Vibrato (0x4) speed
    uint8_t  vib_depth;     // Vibrato depth
    uint8_t  vib_pos;       // Vibrato sine table position (0-63)
    uint8_t  arp_param;     // Arpeggio (0x0) high/low nibble semitone param

    uint8_t  triggered;     // Set to 1 on tick 0 when a new note fires (for LEDs)
} Channel;

// Global sequencer / timing state.
typedef struct {
    uint8_t  song_pos;          // Current position in the order table
    uint8_t  pattern_row;       // Current row within the pattern (0-63)
    uint8_t  tick;              // Current tick within the row (0 .. ticks_per_row-1)
    uint8_t  ticks_per_row;     // Speed (default 6); set by effect 0xF with param < 0x20
    uint8_t  bpm;               // Tempo in BPM (default 125); set by effect 0xF param >= 0x20
    int16_t  samples_per_tick;  // How many audio samples make up one sequencer tick
    int16_t  samples_remaining; // Countdown until the next process_tick() call
    Channel  channel[CHANNELS];
} Player;

// One decoded cell (note slot) from the pattern data.
typedef struct {
    uint8_t  sample;  // Sample number (1-31), or 0 if no new sample
    uint16_t period;  // Amiga period (pitch), or 0 if no new note
    uint8_t  effect;  // Effect number (0x0 - 0xF)
    uint8_t  param;   // Effect parameter byte
} Cell;

// =========================================================================
// GLOBALS
// =========================================================================

Module mod;
Player player;

// Double-buffered ring buffers for left and right PWM audio (filled by main loop,
// consumed by the Timer0 ISR at 16 kHz).
uint8_t audio_buf_L[BUF_SIZE];
uint8_t audio_buf_R[BUF_SIZE];
volatile uint8_t rd_ptr = 0;  // Read pointer ? advanced by ISR
uint8_t wr_ptr = 0;           // Write pointer ? advanced by main loop
volatile uint8_t audio_running = 0;

// =========================================================================
// HARDWARE FLASH ABSTRACTION
// =========================================================================

// Reads a single byte from the hardwired AM29F040B flash at 'addr'.
// PORTA = A0-A7, PORTB = A8-A15, PD0-PD2 = A16-A18, PORTC = data (input).
// The two NOPs after writing PORTD give the flash its required address
// setup + access time (max 150 ns; 2 cycles @ 16 MHz ? 125 ns + PORTD write ? 187.5 ns total).
inline uint8_t read_flash(uint32_t addr) {
    PORTA = addr & 0xFF;
    PORTB = (addr >> 8) & 0xFF;
    // Preserve PWM (PD4/PD5) and 74HC595 (PD3/PD6/PD7) pins; only touch PD0-PD2
    PORTD = (PORTD & 0xF8) | ((addr >> 16) & 0x07);

    // Wait for address propagation & flash access time (up to 150ns)
    // At 16MHz, setting PORTD takes 1 cycle, plus 2 nops = ~187.5ns total.
    __asm__ __volatile__ ("nop\n\t" "nop\n\t");

    return PINC;
}

// Reads a big-endian 16-bit word from flash (MOD format is big-endian).
uint16_t read_be16(uint32_t addr) {
    uint8_t hi = read_flash(addr);
    uint8_t lo = read_flash(addr + 1);
    return (hi << 8) | lo;
}

// =========================================================================
// ENGINE ROUTINES
// =========================================================================

// Recalculates samples_per_tick from the current BPM.
// ProTracker formula: samples_per_tick = (SAMPLE_RATE * 5) / (BPM * 2)
//                                      = 40000 / BPM
void update_tick_timing() {
    player.samples_per_tick = 40000 / player.bpm;
}

// Triggers a new note on a channel: resets playback position and
// recalculates the step size from the current period value.
void trigger_note(Channel* ch) {
    ch->position  = 0;
    ch->triggered = 1;
    if (ch->period > 0) {
        ch->step = STEP_CONSTANT / ch->period;
    }
}

// -------------------------------------------------------------------------
// process_effect_tick0()  ? effects that apply only on tick 0 (note onset)
// -------------------------------------------------------------------------
// MOD effect command reference (all are 4-bit hex nibbles, 0x0 .. 0xF):
//
//  0x0 pp  ? Arpeggio: on tick 0, just store param. Actual pitch-cycling
//             happens in process_effect_tick_n().  pp = 0 resets arpeggio.
//  0x3 pp  ? Tone Portamento: store speed and target period. Does NOT
//             trigger a new note ? the pitch slides from the current period
//             to the target. Tick-by-tick sliding happens in tick_n.
//  0x9 pp  ? Sample Offset: start playback pp*256 bytes into the sample.
//  0xB pp  ? Pattern Jump: jump to order-table position pp immediately.
//  0xC pp  ? Set Volume: set channel volume to pp (0-64, clamped).
//  0xD pp  ? Pattern Break: advance to the next pattern, start at row pp
//             (pp is BCD: high nibble*10 + low nibble).
//  0xF pp  ? Set Speed/Tempo: pp < 0x20 sets ticks-per-row (speed);
//             pp >= 0x20 sets BPM.
//  0xE 1y  ? Fine Portamento Up:   raise period by y immediately (tick 0 only).
//  0xE 2y  ? Fine Portamento Down: lower period by y immediately (tick 0 only).
//  0xE Ay  ? Fine Volume Slide Up:   add y to volume (tick 0 only).
//  0xE By  ? Fine Volume Slide Down: subtract y from volume (tick 0 only).
void process_effect_tick0(Channel* ch, Cell* cell) {
    uint8_t eff   = cell->effect;
    uint8_t param = cell->param;
    uint8_t px    = (param >> 4) & 0x0F;  // High nibble of param
    uint8_t py    = param & 0x0F;          // Low nibble of param

    switch (eff) {
        case 0x0:
            // Arpeggio ? store the param; tick_n handles the cycling.
            // param == 0 means "no arpeggio" (normal note).
            if (param != 0) ch->arp_param = param;
            break;

        case 0x3:
            // Tone Portamento ? remember speed and target, but do NOT
            // retrigger the note (handled specially in process_tick()).
            if (param != 0) ch->porta_speed  = param;
            if (cell->period != 0) ch->porta_target = cell->period;
            break;

        case 0x9:
            // Sample Offset ? jump playback head to param * 256 bytes.
            // Stored as 16.16 fixed-point (shift left 16).
            if (param != 0) ch->position = (uint32_t)(param * 256) << 16;
            break;

        case 0xB:
            // Pattern Jump ? set song position; row rolls over to 0 via the
            // pattern_row = 255 trick (255 + 1 wraps to 0 after the tick++ below).
            player.song_pos = param;
            if (player.song_pos >= mod.num_song_positions) player.song_pos = 0;
            player.pattern_row = 255; // Rollover handled in tick++
            break;

        case 0xC:
            // Set Volume ? clamp to 64.
            ch->volume = (param > 64) ? 64 : param;
            break;

        case 0xD:
            // Pattern Break ? advance to next pattern, start at BCD row pp.
            player.song_pos++;
            if (player.song_pos >= mod.num_song_positions) player.song_pos = 0;
            player.pattern_row = (px * 10 + py) - 1; // -1 because tick++ will add 1
            break;

        case 0xF:
            // Set Speed / Tempo
            if (param < 0x20) {
                // param 1..31 = ticks per row (sequence speed)
                if (param > 0) player.ticks_per_row = param;
            } else {
                // param 32..255 = BPM
                player.bpm = param;
                update_tick_timing();
            }
            break;

        case 0xE:
            // Extended effects (Exy ? x = sub-command, y = value)
            switch (px) {
                case 0x1:
                    // E1y ? Fine Portamento Up: decrease period by y (raises pitch).
                    // Period is inversely proportional to frequency.
                    if (ch->period > 0) {
                        ch->period -= py;
                        if (ch->period < 113) ch->period = 113; // Clamp to highest MOD pitch
                        ch->step = STEP_CONSTANT / ch->period;
                    }
                    break;

                case 0x2:
                    // E2y ? Fine Portamento Down: increase period by y (lowers pitch).
                    if (ch->period > 0) {
                        ch->period += py;
                        if (ch->period > 856) ch->period = 856; // Clamp to lowest MOD pitch
                        ch->step = STEP_CONSTANT / ch->period;
                    }
                    break;

                case 0xA:
                    // EAy ? Fine Volume Slide Up: add y, clamp to 64.
                    ch->volume += py;
                    if (ch->volume > 64) ch->volume = 64;
                    break;

                case 0xB:
                    // EBy ? Fine Volume Slide Down: subtract y, clamp to 0.
                    if (ch->volume >= py) ch->volume -= py; else ch->volume = 0;
                    break;
            }
            break;
    }
}
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
int main(void) {
    cli();           // Disable interrupts during initialisation
    hardware_init(); // Configure I/O, Timer0 (ISR clock), Timer1 (PWM audio)
    mod_load();      // Parse MOD header from flash, prime player state
    sei();           // Enable interrupts ? Timer0 ISR now fires at 16 kHz
    audio_running = 1;

    // Main loop: continuously fill the audio ring-buffer ahead of the ISR.
    // All audio computation happens here so the ISR stays as short as possible.
    while (1) {
        if (!audio_running) continue;

        // Fill ring-buffer until it is full (one slot must remain empty to
        // distinguish "full" from "empty": wr+1 == rd means full).
        while (((wr_ptr + 1) & (BUF_SIZE - 1)) != rd_ptr) {

            // When the tick's worth of audio samples is exhausted, advance the sequencer.
            if (player.samples_remaining <= 0) {
                process_tick();          // Decode next pattern row / apply effects
                update_leds();           // Sync LED flash to note onsets
                player.samples_remaining = player.samples_per_tick;
            }
            player.samples_remaining--;

            // --- Mix four channels into stereo ---
            // ProTracker hard-pans: channels 1 & 4 (index 0 & 3) ? Left
            //                       channels 2 & 3 (index 1 & 2) ? Right
            int16_t left_mix  = 0;
            int16_t right_mix = 0;

            for (int ch = 0; ch < CHANNELS; ch++) {
                Channel* chn = &player.channel[ch];
                int8_t   s   = 0; // Signed 8-bit PCM sample from flash

                if (chn->period > 0 && chn->length > 0) {
                    uint32_t pos_int = chn->position >> 16; // Integer part of 16.16 position

                    // --- Loop / End-of-sample handling ---
                    if (pos_int >= chn->length) {
                        if (chn->loop_length > 2) {
                            // Looping sample: wrap position back into the loop region.
                            uint32_t over = pos_int - chn->loop_start;
                            pos_int = chn->loop_start + (over % chn->loop_length);
                            // Write corrected integer position back, preserving fractional bits.
                            chn->position = (pos_int << 16) | (chn->position & 0xFFFF);
                        } else {
                            // One-shot sample: stop the channel.
                            chn->period = 0;
                        }
                    }

                    if (chn->period > 0) {
                        // Fetch signed 8-bit PCM byte from flash and advance position.
                        s = (int8_t)read_flash(chn->data_offset + pos_int);
                        chn->position += chn->step;
                    }
                }

                // Apply volume scaling: volume 0-64, so shift right 6 bits (divide by 64).
                int16_t mixed = (s * chn->volume) >> 6;

                // Hard-pan as per ProTracker LRRL channel assignment.
                if (ch == 0 || ch == 3) left_mix  += mixed;
                else                    right_mix += mixed;
            }

            // Halve each mix to prevent clipping when two channels are at full volume,
            // then add 128 to convert from signed to unsigned (0-255) for PWM.
            left_mix  = (left_mix  >> 1) + 128;
            right_mix = (right_mix >> 1) + 128;

            audio_buf_L[wr_ptr] = (uint8_t)left_mix;
            audio_buf_R[wr_ptr] = (uint8_t)right_mix;

            wr_ptr = (wr_ptr + 1) & (BUF_SIZE - 1);
        }
    }

    return 0; // Never reached; satisfies the C standard for main()
}

// =========================================================================
// INTERRUPT SERVICE ROUTINE ? Timer0 Compare Match (fires @ 16,000 Hz)
// =========================================================================
// Writes the next buffered stereo sample frame to the PWM compare registers.
// Kept minimal to minimise jitter: just two register writes and a pointer bump.

ISR(TIMER0_COMP_vect) {
    if (rd_ptr != wr_ptr) {
        OCR1A = audio_buf_L[rd_ptr]; // Left  channel ? OC1A / PD5
        OCR1B = audio_buf_R[rd_ptr]; // Right channel ? OC1B / PD4
        rd_ptr = (rd_ptr + 1) & (BUF_SIZE - 1);
    }
}

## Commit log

2026-02-22 Schematic updated
    [avr-mod-player.kicad_pcb, avr-mod-player.kicad_sch]
2026-03-02 Schematic migrated to KiCad 9
    [avr-mod-player.kicad_pcb]
2026-03-04 PCB added to schematic folder
    [avr-mod-player.kicad_pcb, avr-mod-player.kicad_sch]
2026-03-05 Speaker extension board schematic and PCB added
    [speaker-board.kicad_pcb, speaker-board.kicad_sch]
2026-03-05 Schottky diode added to ISP header for protection
    [avr-mod-player.kicad_pcb, avr-mod-player.kicad_sch]
2026-03-05 Schematic: Silkscreen updated on boards
    [avr-mod-player.kicad_pcb, speaker-board.kicad_pcb, speaker-board.kicad_sch]
2026-03-07 Footprints updated, MPLAB X IDE build configurations updated
    [speaker-board.kicad_pcb, speaker-board.kicad_sch]
